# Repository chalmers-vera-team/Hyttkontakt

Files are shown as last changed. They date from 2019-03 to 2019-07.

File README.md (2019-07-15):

# Hyttkontakt
Contact between the chassi's inside and outside. Using a Deutsch DT15-12PA and JST-EH (2.50 mm pitch). 

## Pinout 
1. 12V
2. Deadman 
3. Startmotor
4. Tachometer
5. Hallsensor
6. NC
7. TX
8. RX
9. Camera
10. Batteryrelay 12V
11. Batteryrelay 
12. GND

## Emergency stop rev 1.5
The emergency stop is inline with HMI and battery relay button. The power is going through the emergency button and back again to battery relay input and HMI. The HMI requires power directly from the battery and it is why this is done. 

## VISSS

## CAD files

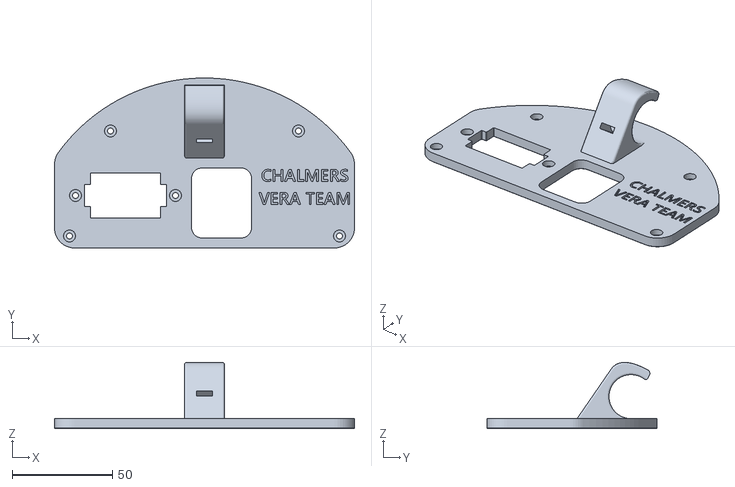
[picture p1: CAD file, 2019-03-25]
AdapterChassiContact.stl
150.0 x 85.0 x 33.1

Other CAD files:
AdapterChassiContact.ipt

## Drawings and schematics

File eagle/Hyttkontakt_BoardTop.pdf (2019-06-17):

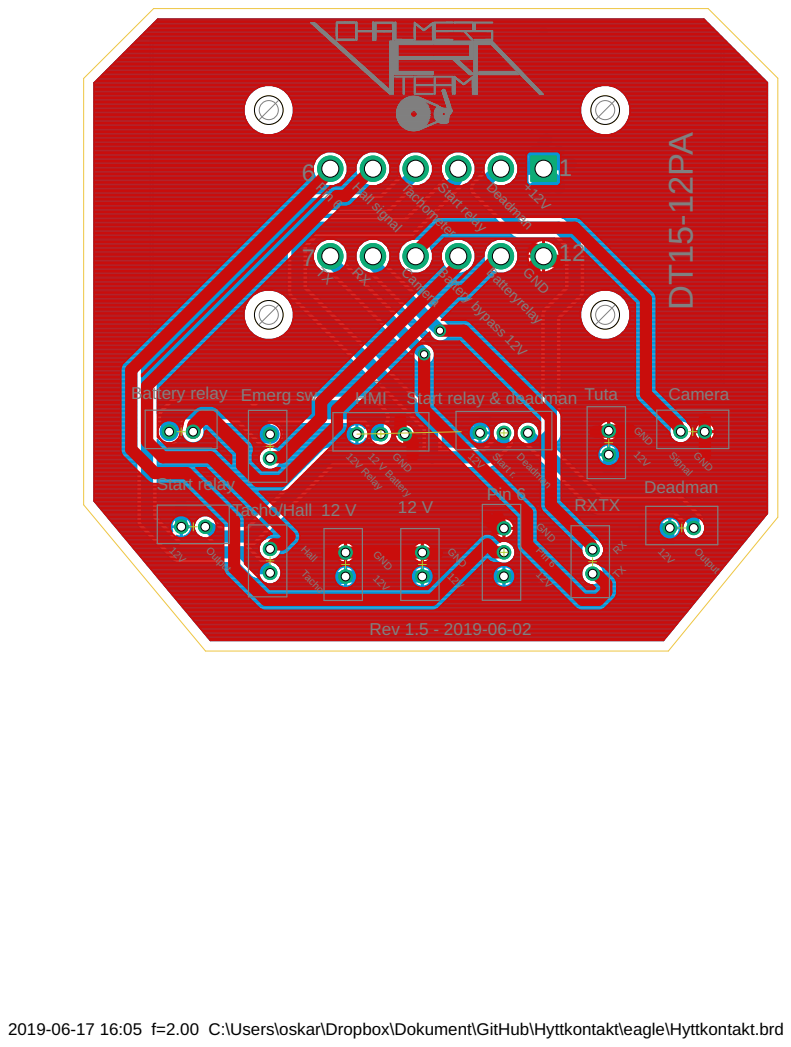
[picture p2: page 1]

Start r. Start relay & deadman

Tacho Hal Start relay

Deadman

Pin 6

2019-06-17 16:05 f=2.00 C:\Users\oskar\Dropbox\Dokument\GitHub\Hyttkontakt\eagle\Hyttkontakt.brd

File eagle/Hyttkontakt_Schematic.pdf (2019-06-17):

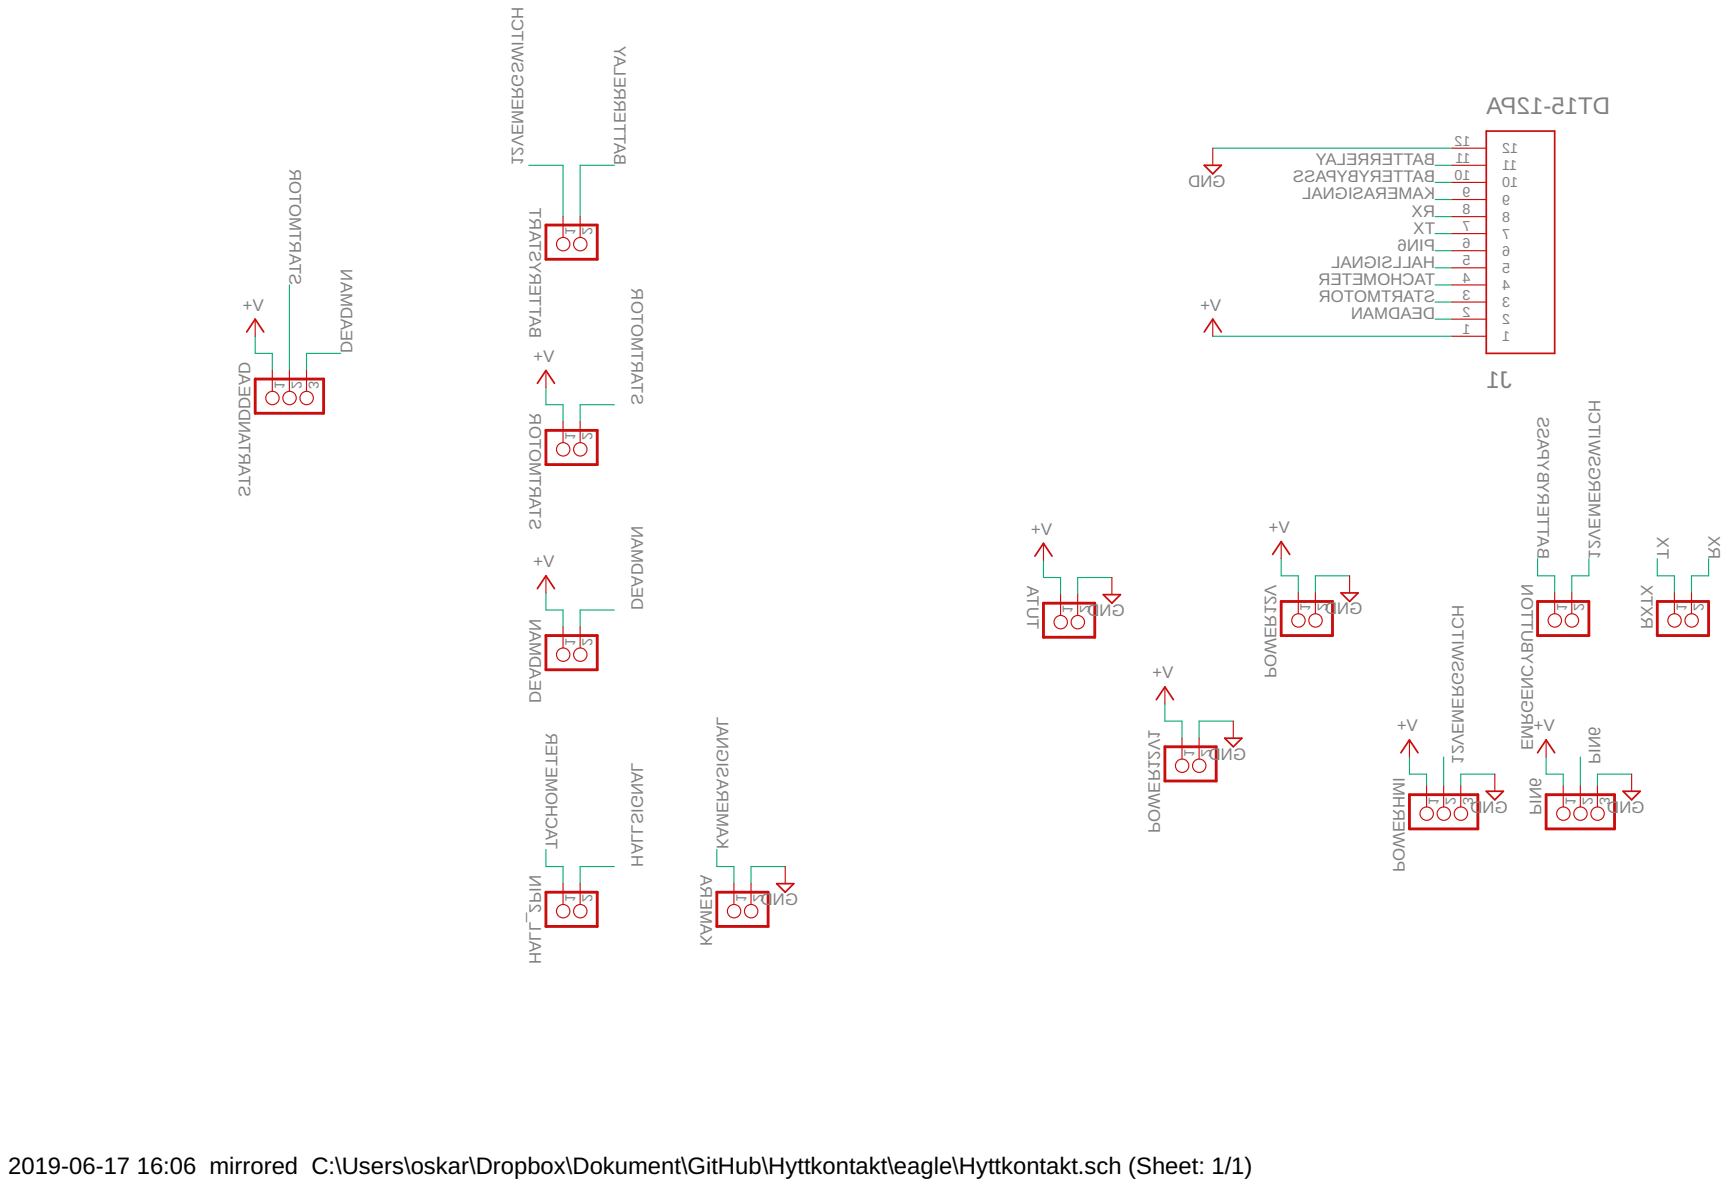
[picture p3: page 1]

2019-06-17 16:06 mirrored C:\Users\oskar\Dropbox\Dokument\GitHub\Hyttkontakt\eagle\Hyttkontakt.sch (Sheet: 1/1)

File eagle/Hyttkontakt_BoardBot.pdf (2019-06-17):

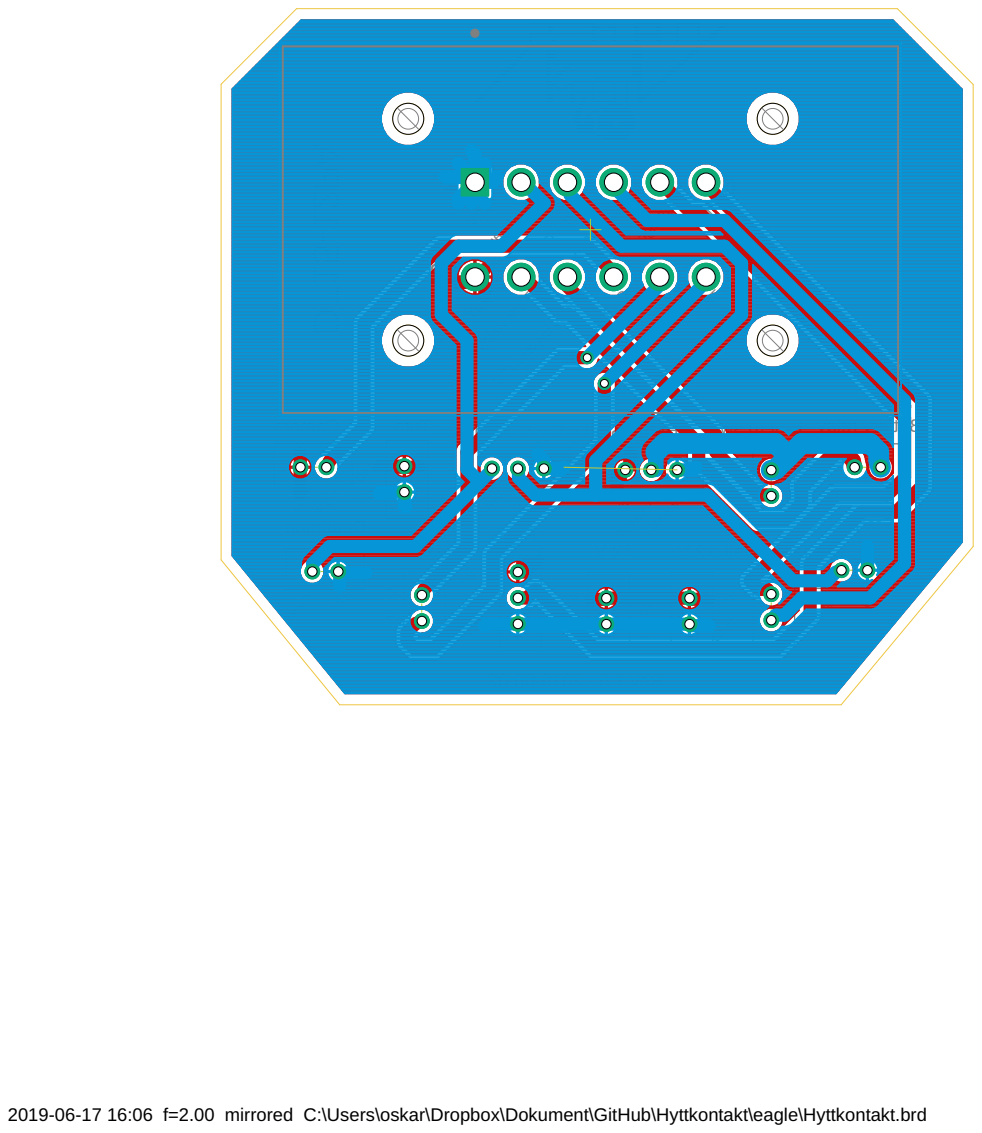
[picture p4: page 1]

Tacho Hal yal er tr at S

2019-06-17 16:06 f=2.00 mirrored C:\Users\oskar\Dropbox\Dokument\GitHub\Hyttkontakt\eagle\Hyttkontakt.brd

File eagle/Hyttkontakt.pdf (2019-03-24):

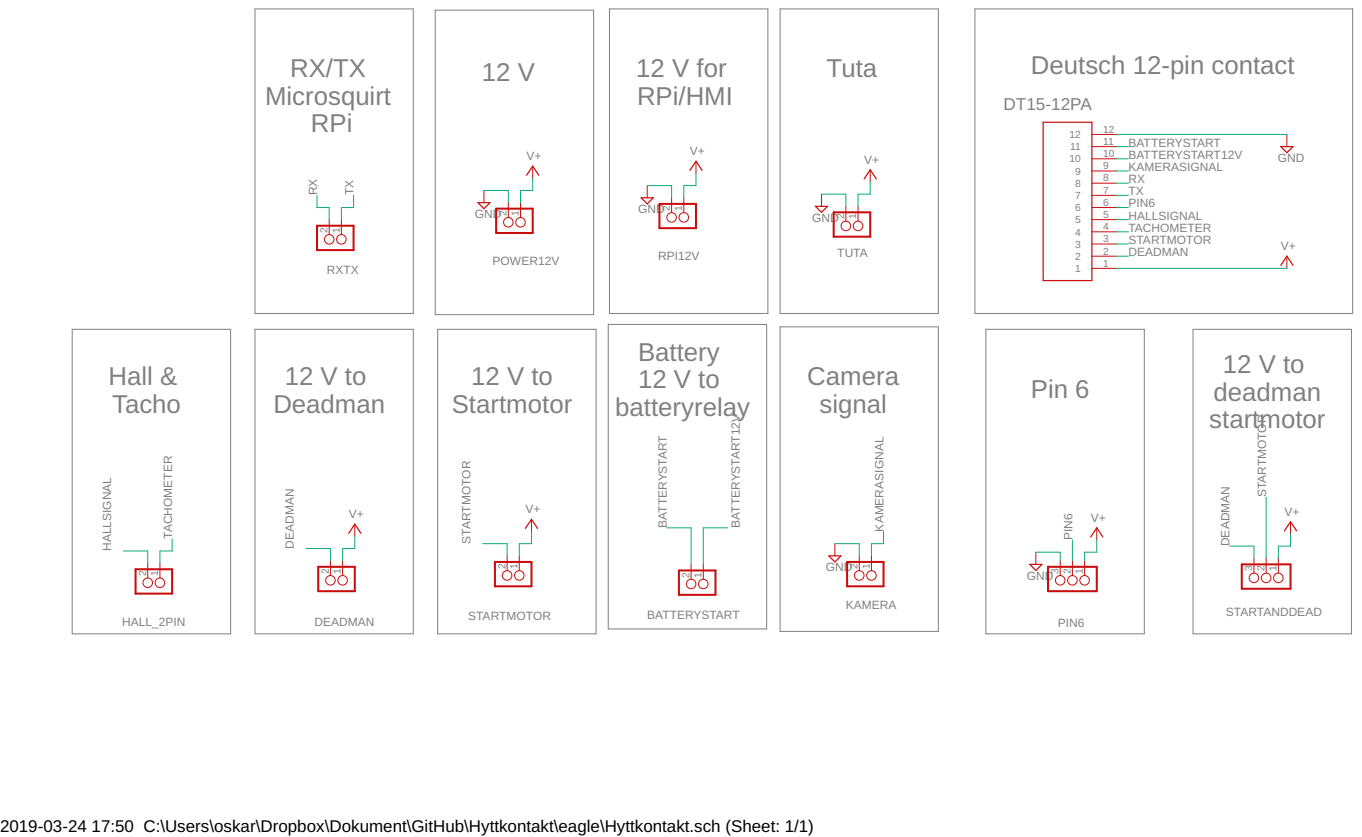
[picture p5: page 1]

2019-03-24 17:50 C:\Users\oskar\Dropbox\Dokument\GitHub\Hyttkontakt\eagle\Hyttkontakt.sch (Sheet: 1/1)

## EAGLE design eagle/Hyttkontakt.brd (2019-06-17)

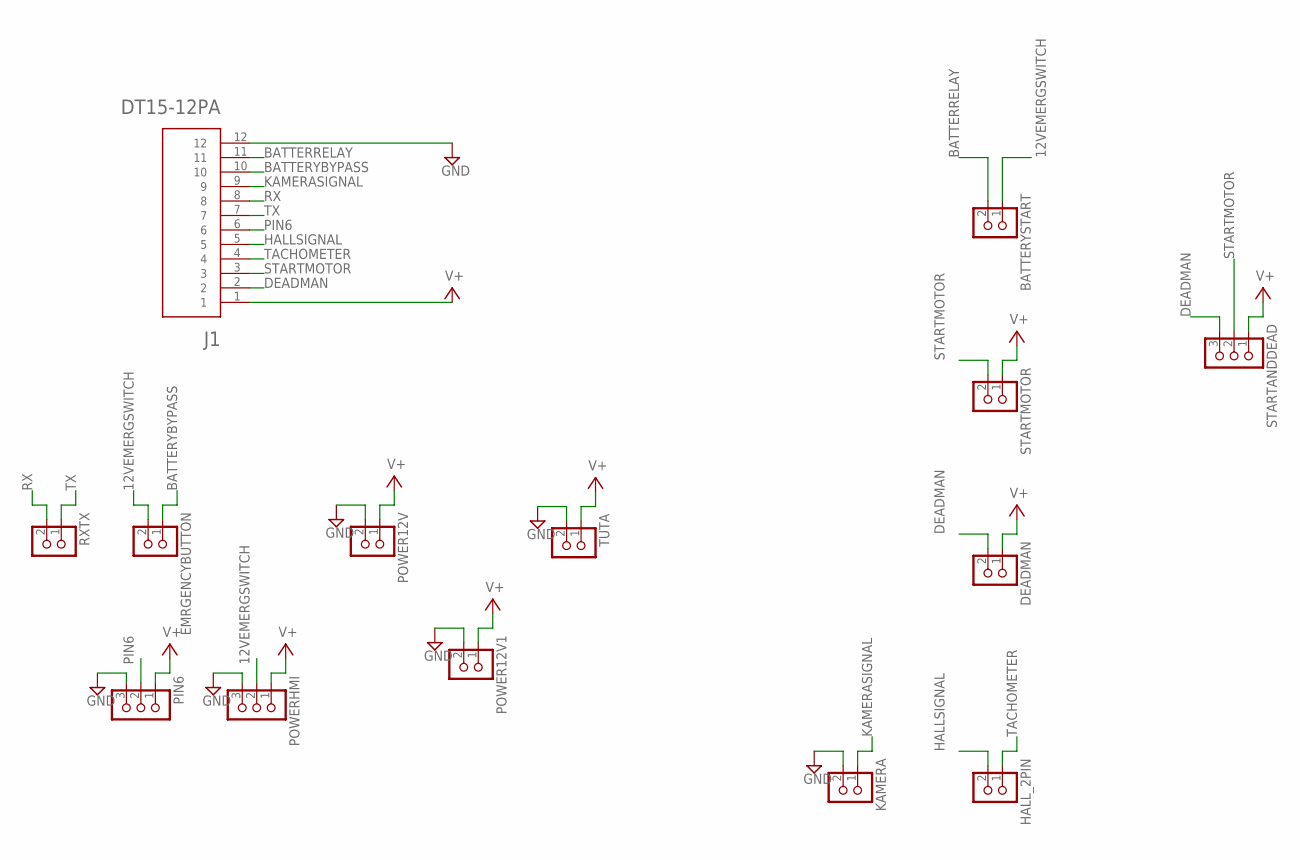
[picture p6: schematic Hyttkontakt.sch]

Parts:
BATTERYSTART: EH_B2B-EH; B2B-EH
DEADMAN: EH_B2B-EH; B2B-EH
EMRGENCYBUTTON: EH_B2B-EH; B2B-EH
HALL_2PIN: EH_B2B-EH; B2B-EH
J1: DT15-12PA; TE_DT15-12PA
KAMERA: EH_B2B-EH; B2B-EH
PIN6: EH_B3B-EH; B3B-EH
POWER12V, POWER12V1: EH_B2B-EH; B2B-EH
POWERHMI: EH_B3B-EH; B3B-EH
RXTX: EH_B2B-EH; B2B-EH
STARTANDDEAD: EH_B3B-EH; B3B-EH
STARTMOTOR: EH_B2B-EH; B2B-EH
TUTA: EH_B2B-EH; B2B-EH

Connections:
12VEMERGSWITCH: BATTERYSTART.1, EMRGENCYBUTTON.2, POWERHMI.2
BATTERRELAY: BATTERYSTART.2, J1.11
BATTERYBYPASS: EMRGENCYBUTTON.1, J1.10
DEADMAN: DEADMAN.2, J1.2, STARTANDDEAD.3
GND: J1.12, KAMERA.2, PIN6.3, POWER12V.2, POWER12V1.2, POWERHMI.3, TUTA.2
HALLSIGNAL: HALL_2PIN.2, J1.5
KAMERASIGNAL: J1.9, KAMERA.1
PIN6: J1.6, PIN6.2
RX: J1.8, RXTX.2
STARTMOTOR: J1.3, STARTANDDEAD.2, STARTMOTOR.2
TACHOMETER: HALL_2PIN.1, J1.4
TX: J1.7, RXTX.1
V+: DEADMAN.1, J1.1, PIN6.1, POWER12V.1, POWER12V1.1, POWERHMI.1, STARTANDDEAD.1, STARTMOTOR.1, TUTA.1

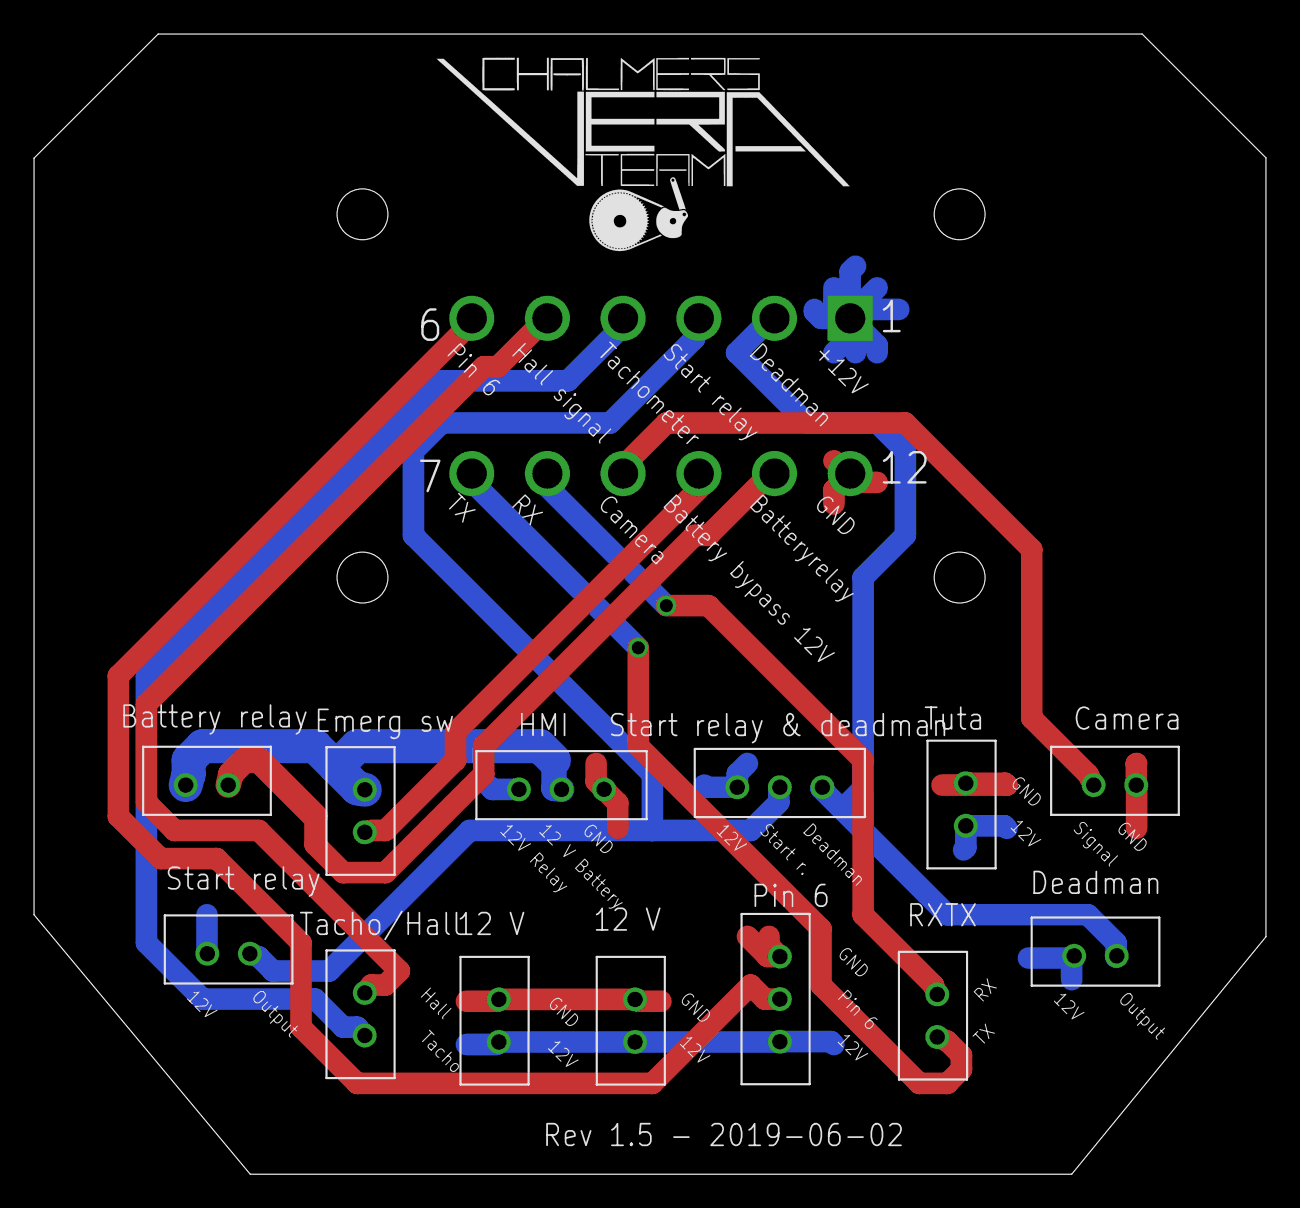
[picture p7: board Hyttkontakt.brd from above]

Board: 2 copper layers, 72.4 x 67.0 mm, 14 parts (1 on the bottom side), 13 nets.

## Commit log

2019-03-24 Rev 1.4
    [AdapterChassiContact.ipt, Hyttkontakt.brd, Hyttkontakt.sch]
2019-03-24 Updated layout (schematic)
    Just updated the layout in the schematic. More clean now
    [Hyttkontakt.brd, Hyttkontakt.sch]
2019-03-24 Create Hyttkontakt.pdf
    Created an pdf from schematic
2019-03-24 Added cableholder
    Added a cableholder on the 3D printed adapter.
    [AdapterChassiContact.ipt, AdapterChassiContact.stl]
2019-03-24 Added cable strip hole
    [AdapterChassiContact.ipt]
2019-03-25 Added hole for cable strip
    [AdapterChassiContact.stl]
2019-06-17 Bypass and easier connections
    - HMI now goes on batterybypass connection
    - Emergency button has its own connection in serie with HMI and Battery relay button
    [Hyttkontakt.brd, Hyttkontakt.sch]
